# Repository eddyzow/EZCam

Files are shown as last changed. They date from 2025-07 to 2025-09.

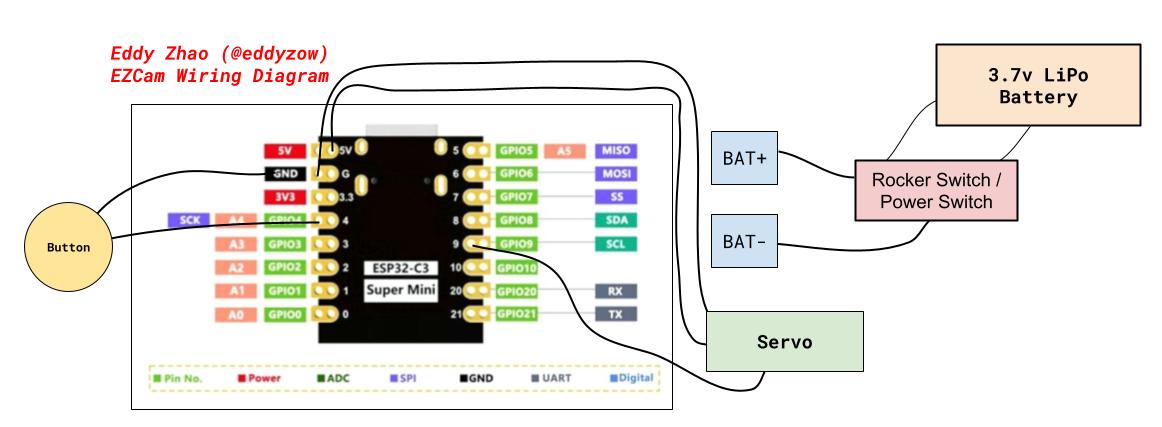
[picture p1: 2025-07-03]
EZCam Wiring Diagram.jpg

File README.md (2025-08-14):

# EZCam
A 3D-printed instant camera. Uses the Jollylook Instant Mini Film Development Unit for film processing. Has hand-cranked roller mechanism and 100mm focal point lens. Runs on Instax Mini Film.

I created this project because I was interested in how cameras that print pictures worked. It turns out they actually don't print but spread a layer of photochemical over the undeveloped film. This made it possible to do this mechanically, and thus the 3D printed camera was born. I also wanted to make and bring a project to Undercity that could generate real tangible versions of memories.

Created by Eddy Zhao (@eddyzow) in June/July 2025 for Hack Club's Highway program.





I made this project

## Electronics / Firmware

The entire camera is mechanical except for the shutter. A servo motor with a shutter attachment is wired to the battery power and ground and the signal pin leads to a GPIO pin on a Seeed XIAO ESP32C3. When the servo rotates, it either covers or uncovers the shutter hole. The servo is controlled by the pressing of a pushdown button. Firmware is extremely simple and written in Arduino.



# Bill of Materials

For a full version, see [this Google Sheet!](https://docs.google.com/spreadsheets/d/1fVYDHt2o4dfsim73XuQ8pmEY-w4QKgZgS4fphIEgDbE/edit?usp=sharing)

Update V3 (7/8): Walmart has a shipping fee which makes Amazon cheaper for buying film

| Item Name | Purpose | Item Source | Quantity | Unit Cost (includes taxes) | Cost |
|:---|:---|:---|:---|:---|:---|
| [Seeed XIAO ESP32C3](https://www.amazon.com/Seeed-Studio-XIAO-ESP32C3-Microcontroller/dp/B0B94JZ2YF) | Brains controlling the shutter/button | Amazon | 1 | $9.79 | $9.79 |
| [4" Focal Length Glass Lens](https://www.amazon.com/dp/B0CPCQ7NCZ) | Camera lens | Amazon | 1 | $9.07 | $9.07 |
| [SG90 Micro Servo Motor](https://www.amazon.com/WWZMDiB-SG90-Control-Servos-Arduino/dp/B0BKPL2Y21) | Servo motor drives the shutter that covers the lens and blocks out light | Amazon | 1 | $7.43 | $7.43 |
| [3.7V 2200mAh LiPo Battery](https://www.amazon.com/OXWINOU-Battery-103450-Rechargeable-1-Pack/dp/B0CTQ6VBB6) | Rechargeable battery powering the Seeed + motor | Amazon | 1 | $10.60 | $10.60 |
| [Jollylook Instant Mini Film Development Unit](https://www.amazon.com/Jollylook-Instant-Development-compatable-Cameras/dp/B0BYTD4T8K) | Manual development unit for Instax film, heart of project | Jollylook | 1 | $47.81 | $47.81 |
| [Fujifilm INSTAX Instant Film - 20 Pack](https://www.amazon.com/gp/product/B09SQSMHYS)|Covers testing and pictures for a trip to Undercity + more | Amazon | 1 | $23.35 | $23.35 |
| **TOTAL** | | | **8** | | **$108.05** |

BOM Cuts so far:	
- New deal at walmart that didn't exist previously let me lower the BOM to a more reasonable 40 pictures at a similar rate. 
- Rocker switch converted to Pushbutton Latch from Pomodoro Timer	
- Button will also be salvaged from Pomodoro Timer	
- Can be conservative on the solder -- probably have enough to last me 	
- PLA filament will be paid for out of pocket

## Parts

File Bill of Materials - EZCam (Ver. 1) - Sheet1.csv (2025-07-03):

Bill of Materials / EZCam
Eddy Zhao
Version 1.0 - 3 July 2025 | Note: Amazon used because AliExpress won't arrive on time and I'm gone for 16 days after I leave for Undercity
Item Name | Purpose | Item Source | Quantity | Unit Cost (includes taxes) | Cost
ELEGOO PLA (Black) 1kg Filament | need a significant amount of filament to run this | Amazon | 1 | $13.38 | $13.38
Seeed XIAO ESP32C3 | Brains controlling the shutter/button | Amazon | 1 | $9.79 | $9.79
4" Focal Length Glass Lens | Camera lens | Amazon | 1 | $9.07 | $9.07
SG90 Micro Servo Motor | Servo motor drives the shutter that covers the lens and blocks out light | Amazon | 1 | $7.43 | $7.43
3.7V 2200mAh LiPo Battery | Rechargeable battery powering the Seeed + motor | Amazon | 1 | $10.60 | $10.60
Jollylook Instant Mini Film Development Unit | Manual development unit for Instax film, heart of project | Amazon (Jollylook) | 1 | $47.81 | $47.81
Fujifilm INSTAX Instant Film - 60 Pack | 3 times the film and only 1.5 times the price. Covers testing and pictures for a trip to Undercity + more | Target | 1 | $42.49 | $42.49
 |  |  |  |  | $0.00
 |  |  |  |  | $0.00
 |  |  |  |  | $0.00
 |  |  |  |  | $0.00
TOTAL |  |  | 7 |  | $140.57
BOM Cuts so far:
- Rocker switch converted to Pushbutton Latch from Pomodoro Timer
- Button will also be salvaged from Pomodoro Timer
- Can be conservative on the solder -- probably have enough to last me

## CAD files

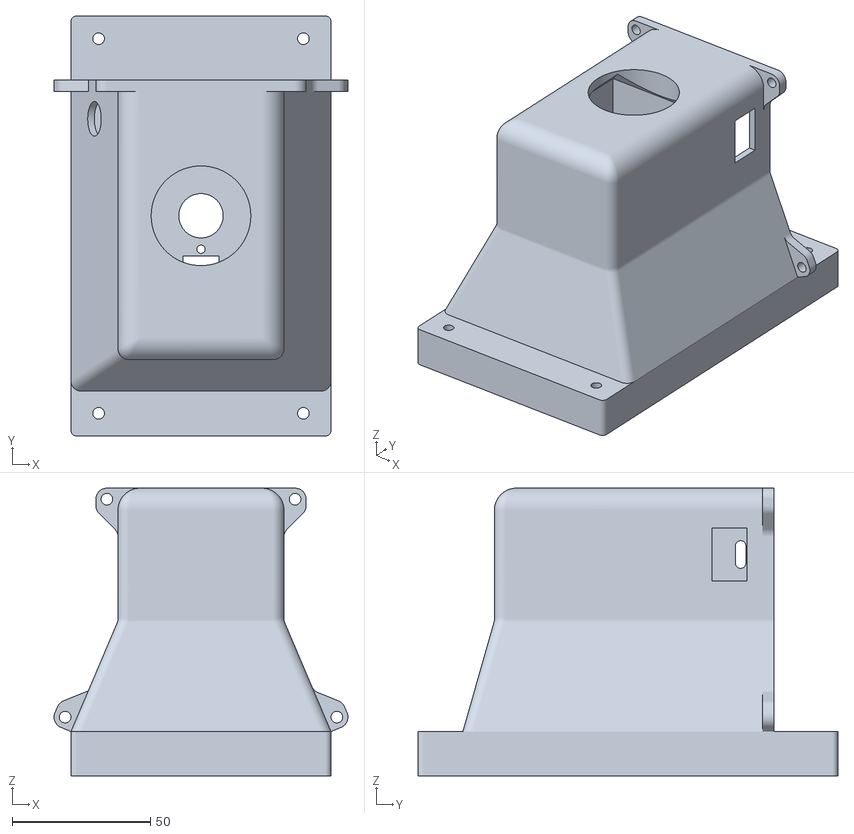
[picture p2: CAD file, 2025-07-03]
cad/Main Body.stl
106.2 x 151.8 x 104.0

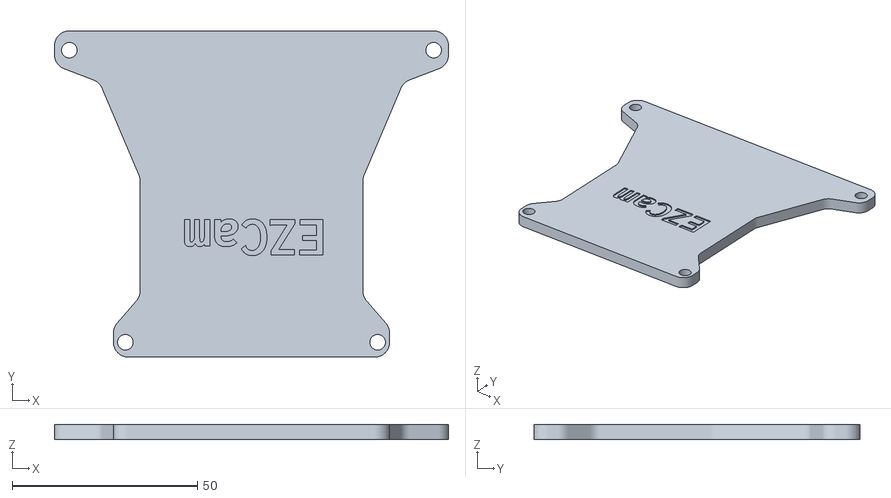
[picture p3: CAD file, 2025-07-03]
cad/Electronics Cover.stl
106.2 x 88.0 x 4.00

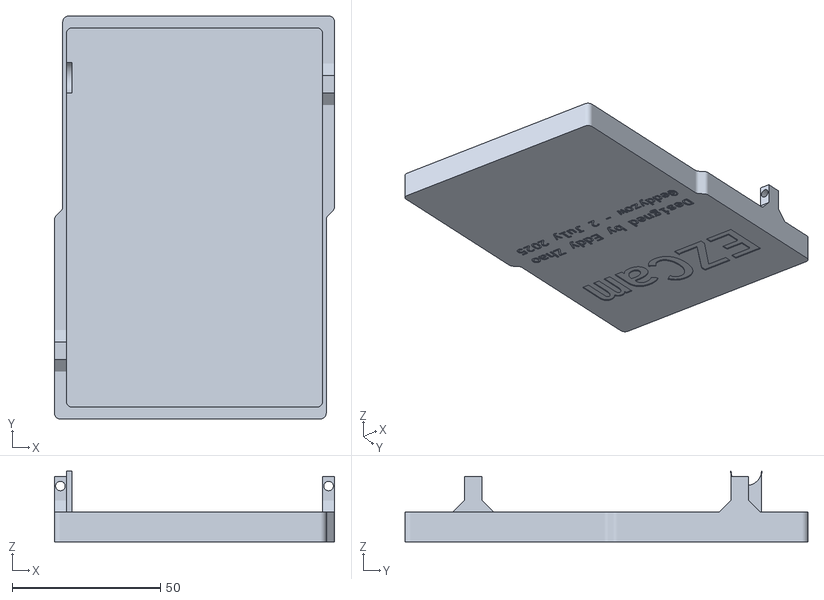
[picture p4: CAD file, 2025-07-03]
cad/Back Case Door.stl
94.4 x 135.8 x 23.8

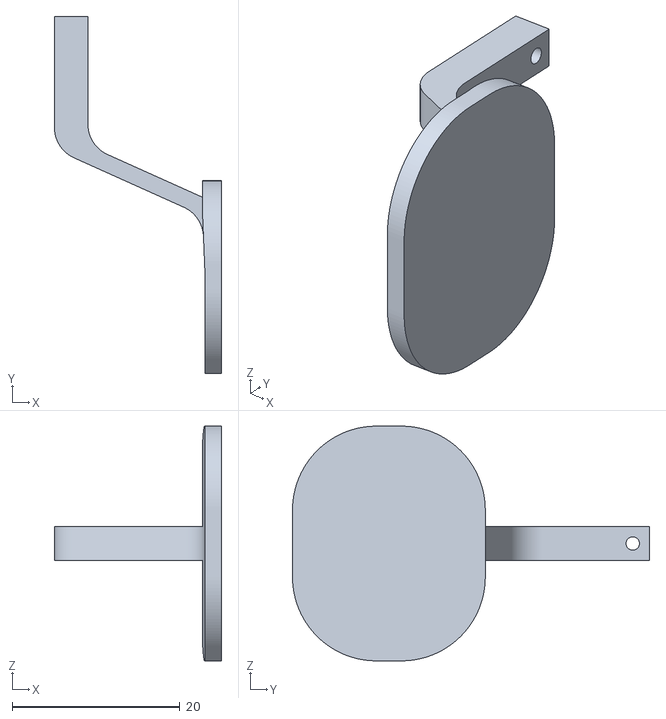
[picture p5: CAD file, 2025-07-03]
cad/Servo Attachment Shutter.stl
20.0 x 42.6 x 28.0

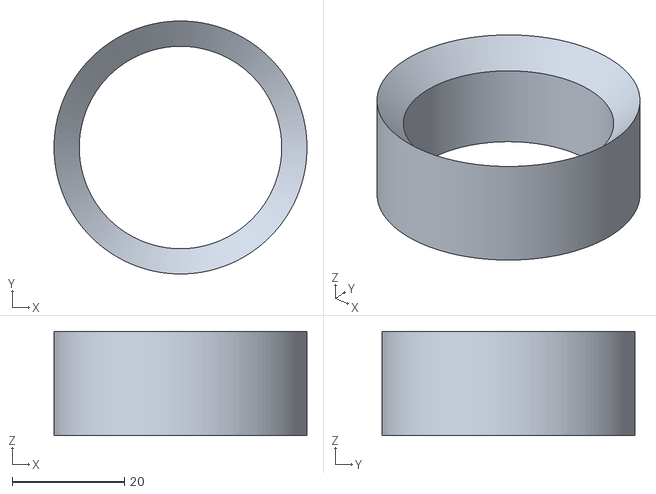
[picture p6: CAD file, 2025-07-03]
cad/Lens Ring.stl
45.0 x 45.0 x 18.5

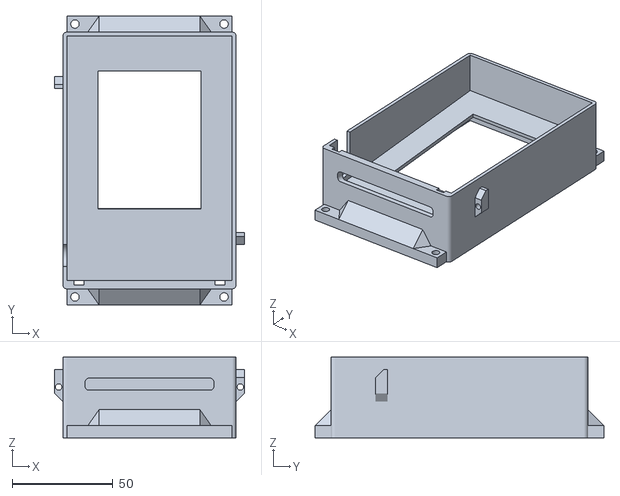
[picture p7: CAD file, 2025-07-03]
cad/Back Case.stl
94.4 x 143.4 x 40.0

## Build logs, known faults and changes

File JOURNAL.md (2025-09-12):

---
title: "EZCam"
author: "Eddy Zhao (@eddyzow)"
description: "A 3D-printed disposable camera that uses the Jollylook Instant Mini Film Development Unit for film processing. Runs on Instax Mini Film."
created_at: "2025-06-30"
---

*Total hours spent: 27* | *Date started: 30 June 2025*

# EZCam
_to capture life's moments_

## entry #10 - 8/14

it's been a month lol but I forgot to add an IRL picture of the camera! so here it is



& a real image it took (the rest weren't great unfortunately)



and a pic from the front!



this was an amazing project and i'd love to do it all over again!

## entry #9 - 7/3

lots of work prepping the repo to be shipped! i changed the appearance so the CAD looks less ugly:



now it's time to submit! after approval i'll quickly buy the parts and get this baby assembled before undercity begins (hopefully)!

_hours spent during session: 2_

## entry #8 - 7/3

after MULTIPLE designs, i ended up with this servo-driven mechanims that might be shady and might or might not work. i'll get to that eventually!



this took SO long and i've basically spent the entire day making this. it'll be probably done tomorrow though!



i won't lie this does look pretty nice... only thing left is to submit and see what kind of pictures it can take! since it was easier than i expected i'm going to request 6 points instead of 10.

_hours spent during session: 5_

## entry #7 - 7/2

finished electronics design, but importantly i don't think the solenoid will work. it's too small and won't push far enough. instead i'll try to think of something else that i can use a motor with.



running with a Seeed XIAO ESP32-C3, on-off rocker switch, and button switch from my Pomodoro Timer project. 

_hours spent during session: 1_

## entry #6 - 7/2

rapid firing these very very short entries to show my progress today! 
here's a pic of the main body starting to come together. i need to add the diaphragm/shutter, lens, and motor mechanism.



_hours spent during session: 2_

## entry #5 - 7/2

case door complete! tight tolerance and a screw mount while also allowing clearance for the crank



_hours spent during session: 2_

## entry #4 - 7/2

mostly finished back case -- this holds the jollylook and film. i now need to make a door for the case, then i will move on to the diaphragm. the goal is to add as much polish as possible!



_hours spent during session: 1_

## entry #3 - 7/2

case work today!



the jollylook can now easily slide into the case without moving around. tomorrow i'll design a light-proof door that seals light away from the interior of the camera. then I'll begin the next stage of the camera: the diaphragm, shutter, and lens.

i'm going to throw a servo motor in the diaphragm where through some mechanism (not determined yet) the shutter will be controlled open and closed. i think the best device for this is a push-pull solenoid, which basically pushes a slug of metal up when voltage is applied and back down when voltage is removed. this [Adafruit push-pull solenoid](https://www.adafruit.com/product/2776) seems like a great product and i'll probably use it in my design! 

_hours spent during session: 3_

## entry #2 - 7/1

i spent many hours today doing more research into the camera.

it seems like the jollylook module has little to no documentation aside from a CAD model that will prove very useful, though it's an STL so there are no dimensions. to make things worse, mounting holes are not in the 3D model so i also don't know how to mount it at all.

i spent many hours trying to create a lightproof case, but it seems like it's too difficult without a physical model of the jollylook as I can't get my parts until I submit the design. i'll be using [Josh Gladstone](https://www.youtube.com/watch?v=n-TAC5FUcVg)'s case design as a result, which is already perfectly aligned to support the Instax Mini. why recreate stuff that already exists? anyways, another huge shoutout to Josh Gladstone, who has been the greatest inspiration for this project. I don't want this to be a full copy of his project, though, so I'm just going to try to make as many of my own parts as possible.

one thing I should look at is how I'm going to wire the battery/microcontroller/servo for the shutter. 




_hours spent during session: 5_

## entry #1 - 6/30

it's time to begin a new project! this is a disposable camera that is mostly 3D printed except for a few important parts (lens, development unit, film, etc). 

i had created this project a few weeks before but scrapped it since I thought it would be way too hard to 3D print a proper development unit. good thing that there are places that sell individual freestanding development units! i've done some research today into the project and deemed that it's definitely doable as long as i lock in.

i don't think this is breaking the rules because 3D print probably wouldn't be able to cleanly process the film anyways, but there is one guy who managed to do it [Toast](https://www.youtube.com/watch?v=dPTo-G7txo4) and [Josh Gladstone](https://www.youtube.com/watch?v=n-TAC5FUcVg) have created excellent videos that show them making disposable cameras with 3D printed parts. of these, Josh Gladstone's design has the Jollylook development unit and is the primary inspiration for my project.

i would like to build off Josh Gladstone's design by motorizing the shutter and adding some small quality of life improvements (shutter button, timer setting, etc). i think i may go for 10 Highway points for this project since it's so incredibly complex and pulling it off would be the greatest thing I've done since my electric scooter.

signing off for now! i'll do some tinkering for now and hopefully grind out the whole day to make the design tomorrow.

_hours spent during session: 2_

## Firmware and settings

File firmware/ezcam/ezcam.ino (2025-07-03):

#include <Servo.h>

/*
  - When the button is NOT pressed, the servo is at 90 degrees
  - When the button IS pressed and held, the servo moves to 0 degrees
  - Servo:
    - Signal (Orange/Yellow wire) -> Pin 9
    - VCC (Red wire)              -> 5V
    - GND (Brown/Black wire)      -> GND
  - Pushbutton:
    - One leg -> Pin 2
    - Other leg -> GND
*/

const int SERVO_PIN = 9;   // The digital PWM pin for the servo's signal wire.
const int BUTTON_PIN = 2;  // The digital pin for the pushbutton.

const int SHUTTER_OPEN_POS = 0;   // Position when the shutter is open.
const int SHUTTER_CLOSED_POS = 90; // Position when the shutter is closed.

Servo shutterServo;

void setup() {
  pinMode(BUTTON_PIN, INPUT_PULLUP);
  shutterServo.attach(SERVO_PIN);
  shutterServo.write(SHUTTER_CLOSED_POS);
}

void loop() {
  int buttonState = digitalRead(BUTTON_PIN);
  if (buttonState == LOW) {
    shutterServo.write(SHUTTER_OPEN_POS);
  } else {
    shutterServo.write(SHUTTER_CLOSED_POS);
  }

  delay(20);
}
